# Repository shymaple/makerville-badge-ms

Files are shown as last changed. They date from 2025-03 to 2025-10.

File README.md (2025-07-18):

- `mkdir badge-workspace`
- `cd badge-workspace`
- `west init -m git@github.com:makerville/makerville-badge.git --mr master`
- `west update`
- `west packages pip --install`
- `west sdk install -t riscv64-zephyr-elf`
- `west blobs fetch hal_espressif`
- `cd makerville-badge`
- `make`
- `make flash monitor`

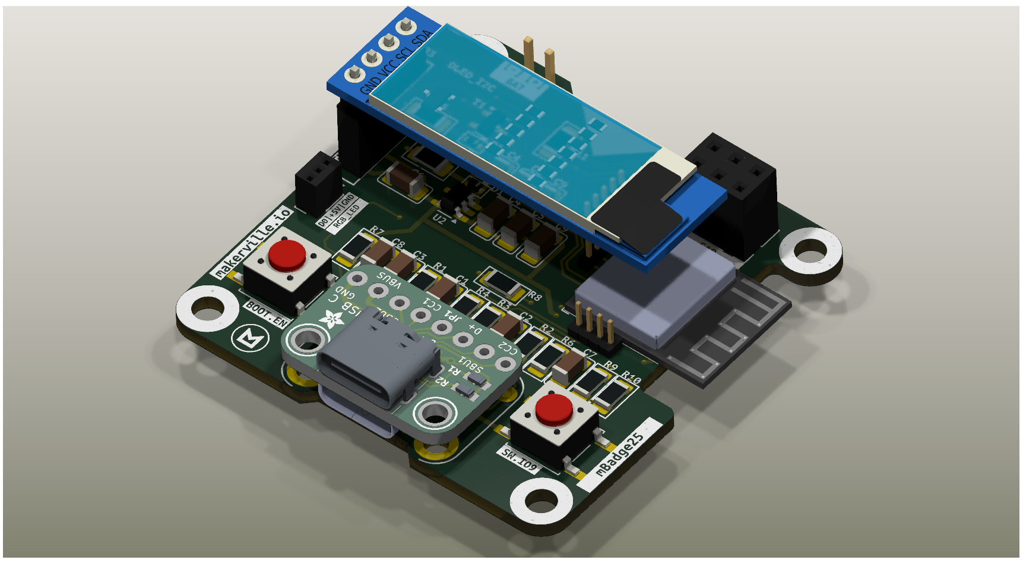
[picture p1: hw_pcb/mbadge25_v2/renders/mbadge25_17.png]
mBadge25_TOP


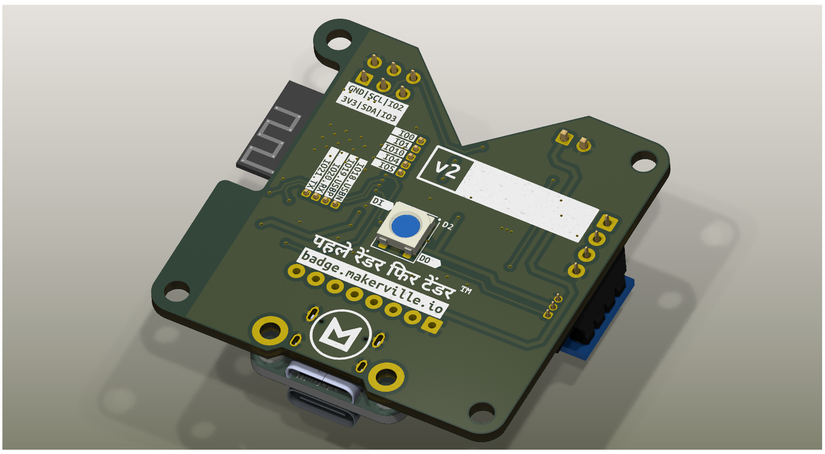
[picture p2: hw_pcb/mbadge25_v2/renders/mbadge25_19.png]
mBadge25_BOT


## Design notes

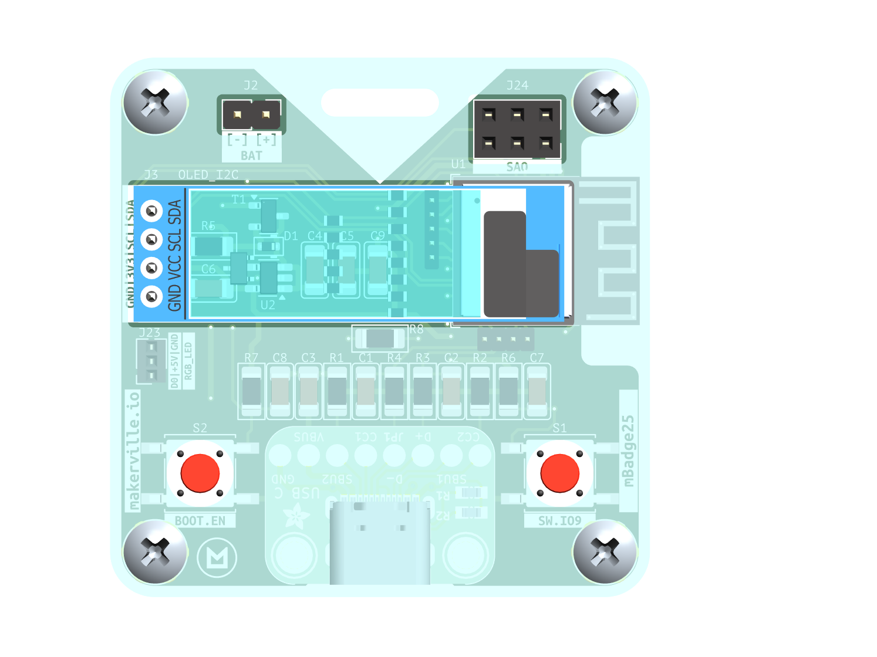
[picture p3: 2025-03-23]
hw_cad/renders/case_04.png

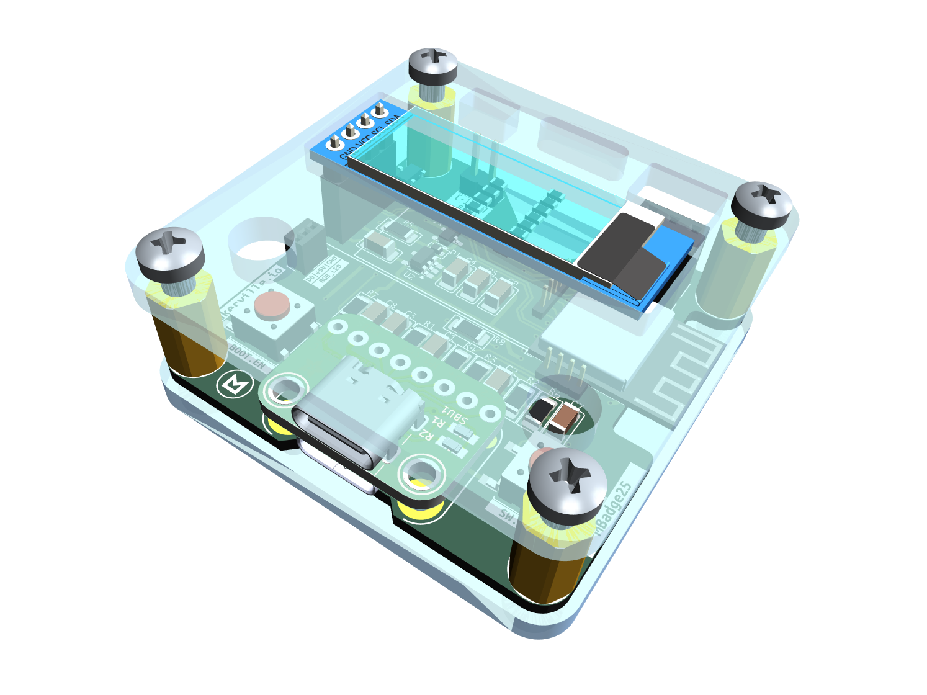
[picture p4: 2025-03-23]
hw_cad/renders/case_02.png

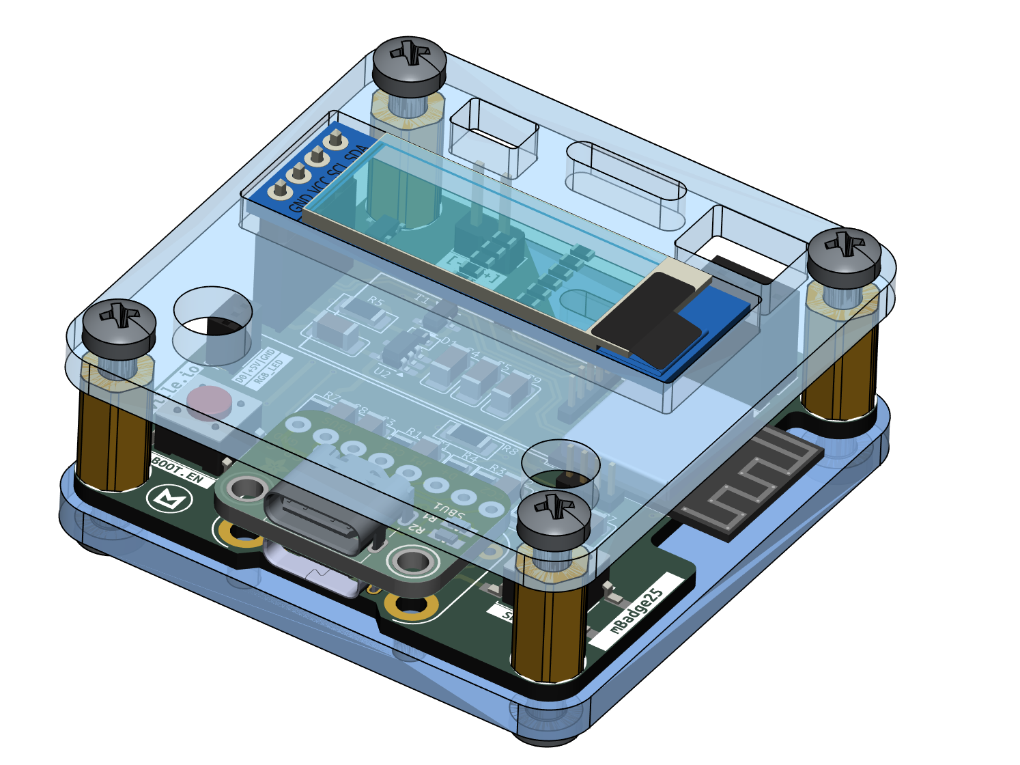
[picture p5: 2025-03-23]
hw_cad/renders/case_01.png

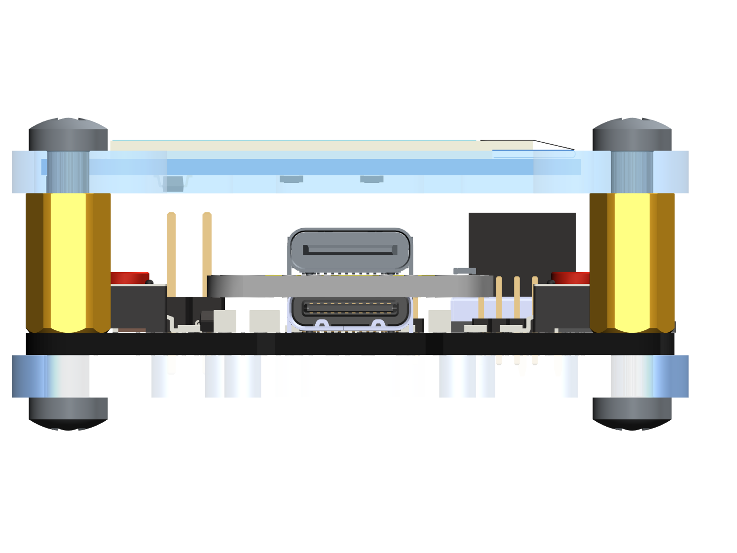
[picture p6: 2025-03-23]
hw_cad/renders/case_03.png

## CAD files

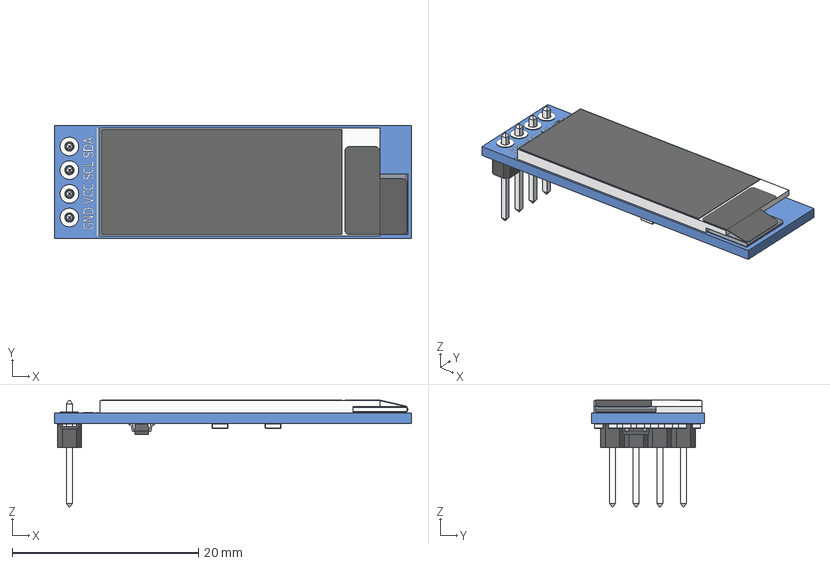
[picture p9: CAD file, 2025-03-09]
datasheets/OLED_0.91_128x32.stp
38.3 x 12.1 x 11.5 mm
OLED_0.91_128x32
Pin Header 4 x 1 TH 2.54mm Pitch
RESC-0603 x 13
2SD0601A

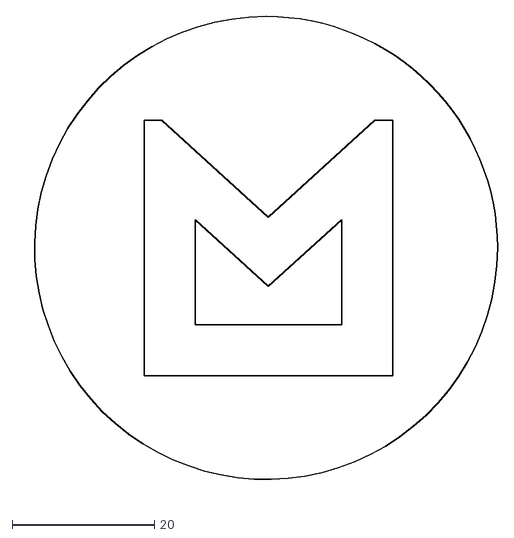
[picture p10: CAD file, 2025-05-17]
hw_pcb/mbadge25_v2/assets/makerville_logo.dxf
67.7 x 67.7

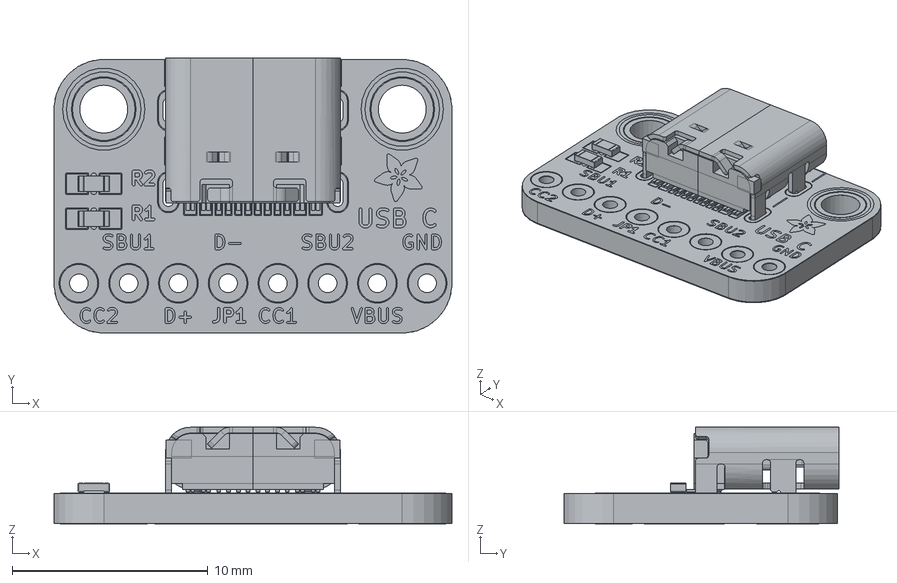
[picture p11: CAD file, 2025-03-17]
hw_pcb/USB-C_breakout/USB-C_BO.FCStd
20.3 x 14.0 x 4.98 mm
R_0603_1608Metric
R_0603_1608Metric001
USB_C_Receptacle_GCT_USB4105-xx-A_16P_TopMnt_Horizontal
USB_C_Receptacle_GCT_USB4105-xx-A_16P_TopMnt_Horizontal001
USB_C_Receptacle_GCT_USB4105-xx-A_16P_TopMnt_Horizontal002
USB_C_Receptacle_GCT_USB4105-xx-A_16P_TopMnt_Horizontal003
USB_C_Receptacle_GCT_USB4105-xx-A_16P_TopMnt_Horizontal004
USB_C_Receptacle_GCT_USB4105-xx-A_16P_TopMnt_Horizontal005
USB_C_Receptacle_GCT_USB4105-xx-A_16P_TopMnt_Horizontal006
USB_C_Receptacle_GCT_USB4105-xx-A_16P_TopMnt_Horizontal007
USB_C_Receptacle_GCT_USB4105-xx-A_16P_TopMnt_Horizontal008
USB_C_Receptacle_GCT_USB4105-xx-A_16P_TopMnt_Horizontal009
USB_C_Receptacle_GCT_USB4105-xx-A_16P_TopMnt_Horizontal010
USB_C_Receptacle_GCT_USB4105-xx-A_16P_TopMnt_Horizontal011
USB_C_Receptacle_GCT_USB4105-xx-A_16P_TopMnt_Horizontal012
USB_C_Receptacle_GCT_USB4105-xx-A_16P_TopMnt_Horizontal013
USB_C_Receptacle_GCT_USB4105-xx-A_16P_TopMnt_Horizontal014
USB_C_Receptacle_GCT_USB4105-xx-A_16P_TopMnt_Horizontal015
USB_C_Receptacle_GCT_USB4105-xx-A_16P_TopMnt_Horizontal016
USB_C_Receptacle_GCT_USB4105-xx-A_16P_TopMnt_Horizontal017
USB_C_Receptacle_GCT_USB4105-xx-A_16P_TopMnt_Horizontal018
USB_C_Receptacle_GCT_USB4105-xx-A_16P_TopMnt_Horizontal019
USB_C_Receptacle_GCT_USB4105-xx-A_16P_TopMnt_Horizontal020
USB_C_Receptacle_GCT_USB4105-xx-A_16P_TopMnt_Horizontal021
USB_C_Receptacle_GCT_USB4105-xx-A_16P_TopMnt_Horizontal022
USB_C_Receptacle_GCT_USB4105-xx-A_16P_TopMnt_Horizontal023
USB_C_Receptacle_GCT_USB4105-xx-A_16P_TopMnt_Horizontal024
USB_C_Receptacle_GCT_USB4105-xx-A_16P_TopMnt_Horizontal025
USB_C_Receptacle_GCT_USB4105-xx-A_16P_TopMnt_Horizontal026
USB_C_Receptacle_GCT_USB4105-xx-A_16P_TopMnt_Horizontal027
USB_C_Receptacle_GCT_USB4105-xx-A_16P_TopMnt_Horizontal028
USB_C_Receptacle_GCT_USB4105-xx-A_16P_TopMnt_Horizontal029
USB_C_Receptacle_GCT_USB4105-xx-A_16P_TopMnt_Horizontal030
USB_C_Receptacle_GCT_USB4105-xx-A_16P_TopMnt_Horizontal031
USB_C_Receptacle_GCT_USB4105-xx-A_16P_TopMnt_Horizontal032
USB_C_Receptacle_GCT_USB4105-xx-A_16P_TopMnt_Horizontal033
USB_C_Receptacle_GCT_USB4105-xx-A_16P_TopMnt_Horizontal034
USB_C_Receptacle_GCT_USB4105-xx-A_16P_TopMnt_Horizontal035
Adafruit USB Type C Downstream Breakout rev B_copper
Adafruit USB Type C Downstream Breakout rev B_copper001
Adafruit USB Type C Downstream Breakout rev B_copper002
Adafruit USB Type C Downstream Breakout rev B_copper003
Adafruit USB Type C Downstream Breakout rev B_copper004
Adafruit USB Type C Downstream Breakout rev B_copper005
Adafruit USB Type C Downstream Breakout rev B_copper006
Adafruit USB Type C Downstream Breakout rev B_copper007
Adafruit USB Type C Downstream Breakout rev B_copper008
Adafruit USB Type C Downstream Breakout rev B_copper009
Adafruit USB Type C Downstream Breakout rev B_copper010
Adafruit USB Type C Downstream Breakout rev B_copper011
Adafruit USB Type C Downstream Breakout rev B_pad
Adafruit USB Type C Downstream Breakout rev B_pad001
Adafruit USB Type C Downstream Breakout rev B_pad002
Adafruit USB Type C Downstream Breakout rev B_pad003
Adafruit USB Type C Downstream Breakout rev B_pad004
Adafruit USB Type C Downstream Breakout rev B_pad005
Adafruit USB Type C Downstream Breakout rev B_pad006
Adafruit USB Type C Downstream Breakout rev B_pad007
Adafruit USB Type C Downstream Breakout rev B_pad008
Adafruit USB Type C Downstream Breakout rev B_pad009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

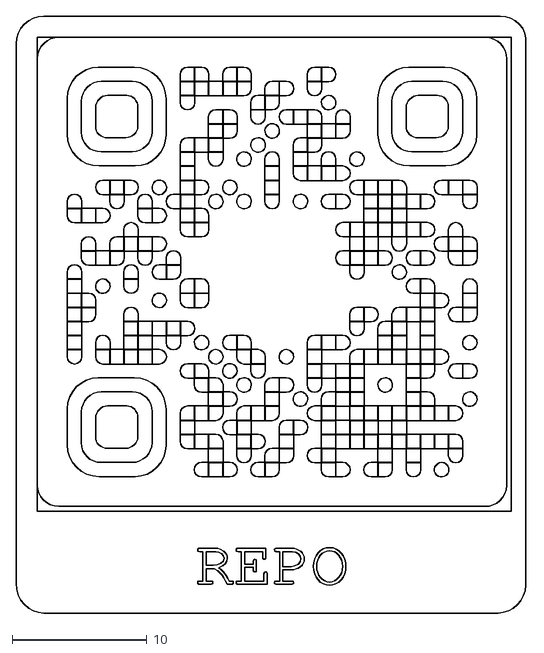
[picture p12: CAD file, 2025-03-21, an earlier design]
hw_pcb/mbadge25_v1/assets/MakervilleBadgeRepo.dxf
37.9 x 44.3

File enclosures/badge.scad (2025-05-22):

include <jl_scad/box.scad>
include <jl_scad/parts.scad>
include <jl_scad/utils.scad>
$fs = $preview?0.5:0.125;
$fa = 1;

$slop = 0.08;
box_sz = [47.5,47.5,10];
$box_outside_color = "#fffb";
$box_inside_color = "#9a9b";
$box_cut_color = "#0000";

// halves=[BOT]
box_make(print=true)
box_shell_base_lid(box_sz,rsides=6,wall_sides=1.6,wall_top=2,base_height=3,rim_height=2,rbot_inside=1,rtop_inside=1)
{
    size = $parent_size;

    // usb c 
    translate([0,0,3])box_part(TOP+FRONT)  box_cutout(rect([12,6]),depth=2,anchor=CENTER);

    // bat cables
    translate([0,0,0])box_part(TOP+BACK)  box_cutout(rect([5,2]),depth=2);

    // display
    translate([-2,12,0])box_part(TOP)  box_cutout(rect([27,12]),depth=2,anchor=FRONT);
    // text
     box_part(TOP, inside=false)
         translate([0,-7,0])Z(-0.4) box_cut() text3d("Makerville", h=2, size=7, atype="ycenter", anchor=BOTTOM);
    // vents
    X(11) box_cut() //for(a = [BACK,FRONT])
        box_part(LEFT) xcopies(3,4,sp=0) cuboid([1.5,8,8],rounding=0.75,anchor=CENTER);

    // screw mounts
    for(a = [BACK+LEFT, FRONT+RIGHT, BACK+RIGHT, FRONT+LEFT])
        M(a * -0.5) position(a) box_screw_clamp(od=6.4,anchor=a,gap=2);
            
    // buttons
    translate([16,-13.5,0])box_part(TOP) box_cut() cyl(d=5,h=15,anchor=CENTER); 
    translate([-16,-13.5,0])box_part(TOP) box_cut() cyl(d=5,h=15,anchor=CENTER); 

}

// buttons
module push_button(){
cylinder(4,4/2,4/2);
cylinder(0.5,5.6/2,5.6/2);
}

translate([50,0,0])push_button();
translate([40,0,0])push_button();

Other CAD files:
hw_pcb/USB-C_breakout/Adafruit USB Type C Downstream Breakout rev B.step

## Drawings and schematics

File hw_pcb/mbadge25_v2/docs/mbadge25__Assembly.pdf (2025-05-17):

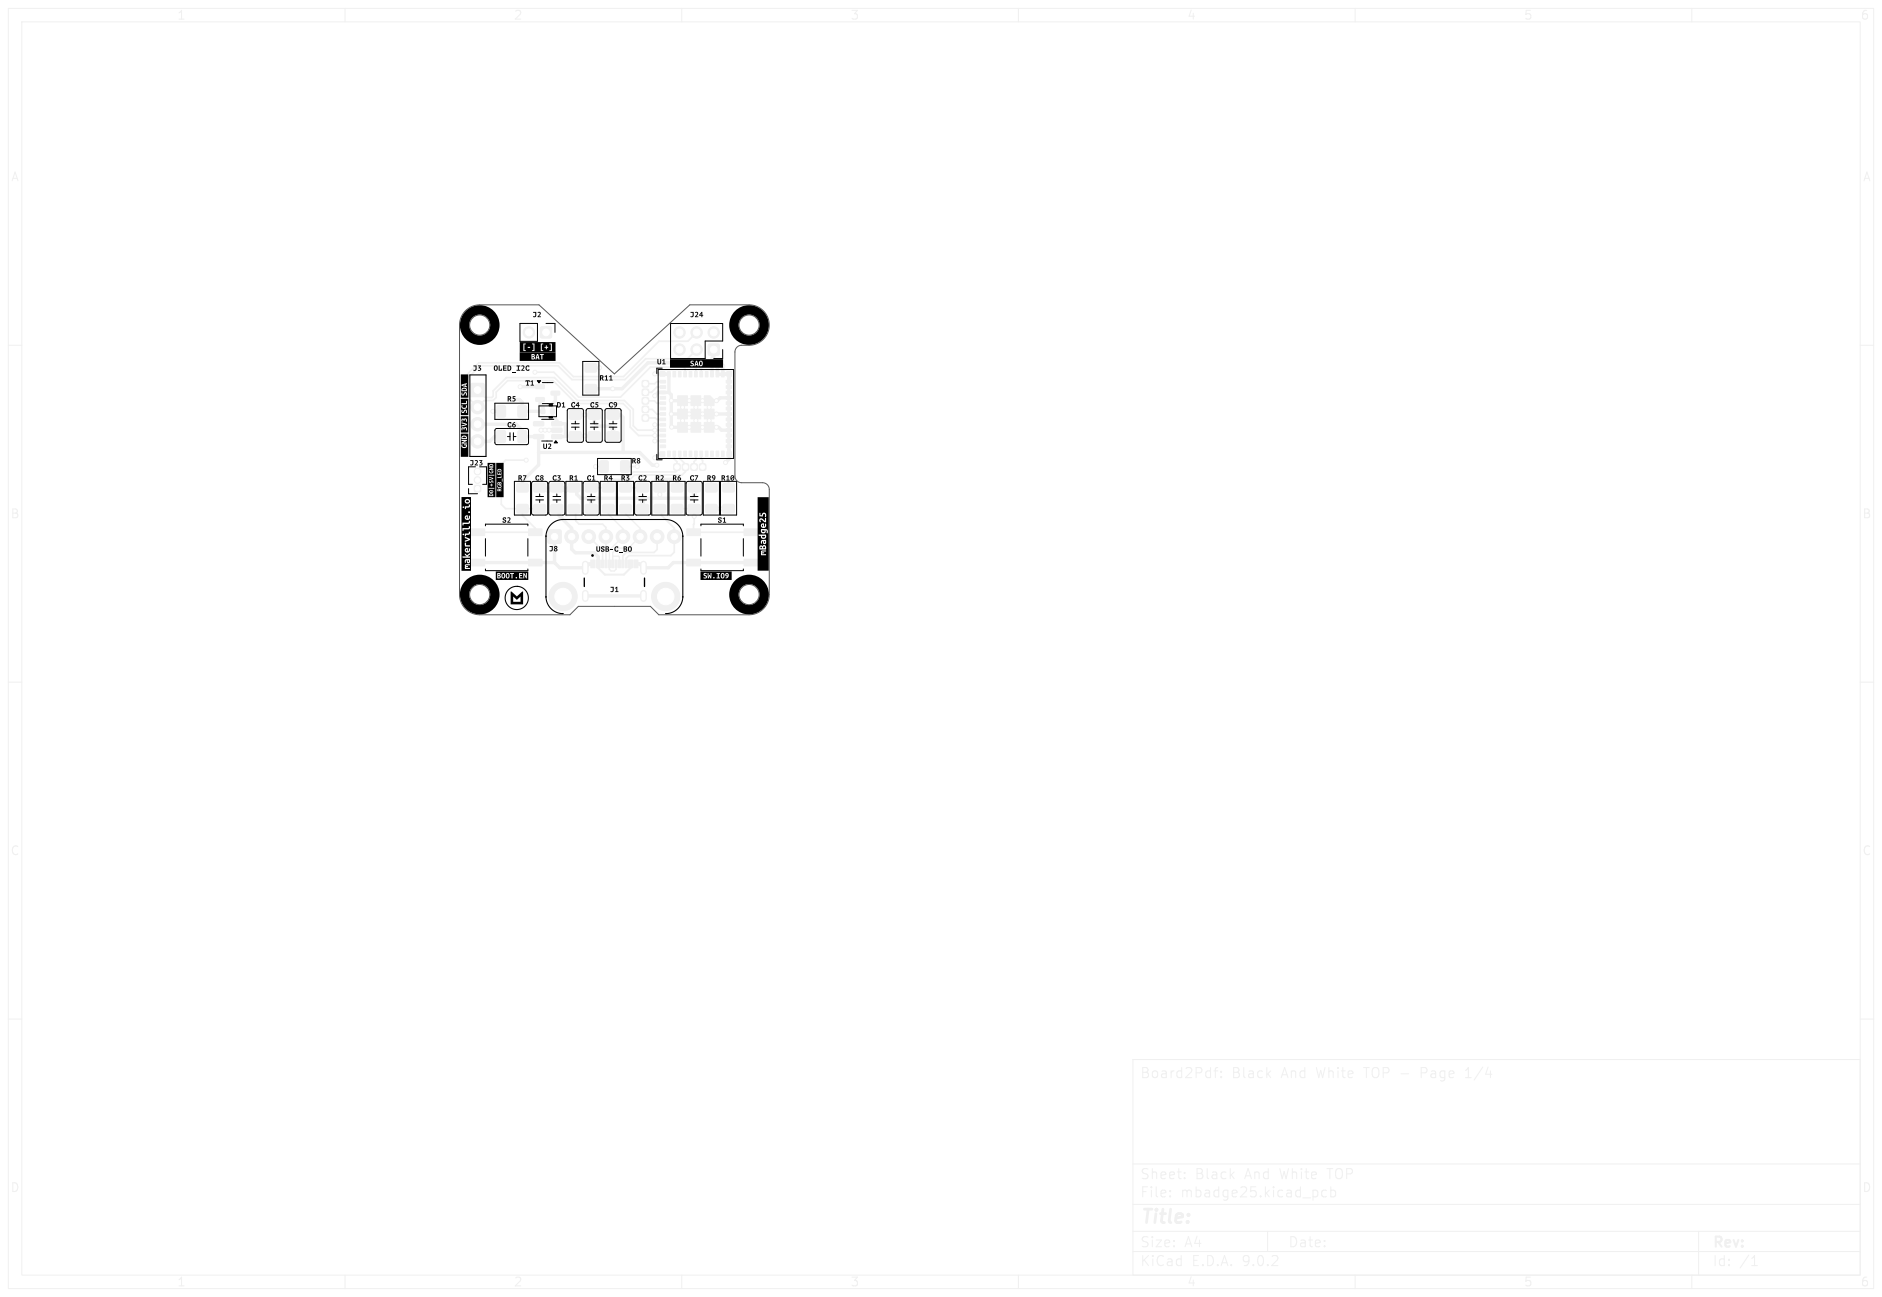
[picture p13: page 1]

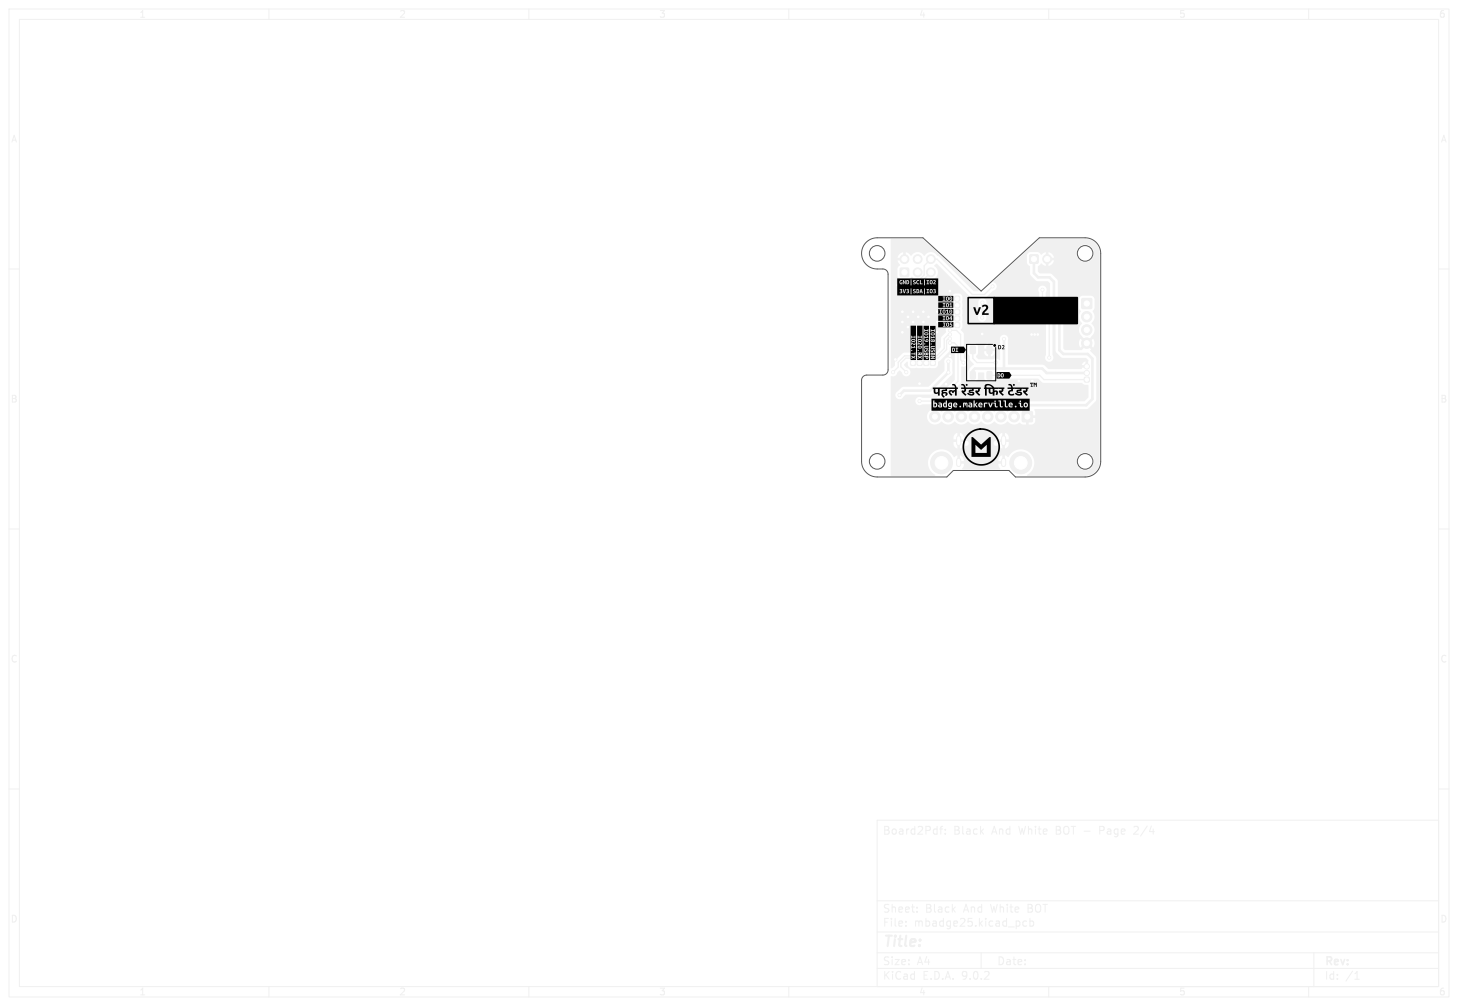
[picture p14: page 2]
D Date: KiCad; E.D.A. 9.0.2 Size: A4; Rev:; Id: /1 Title: File: mbadge25.kicad_pcb Sheet: Black; And; White; BOT Board2Pdf:; Black; BOT -; Page 2/4

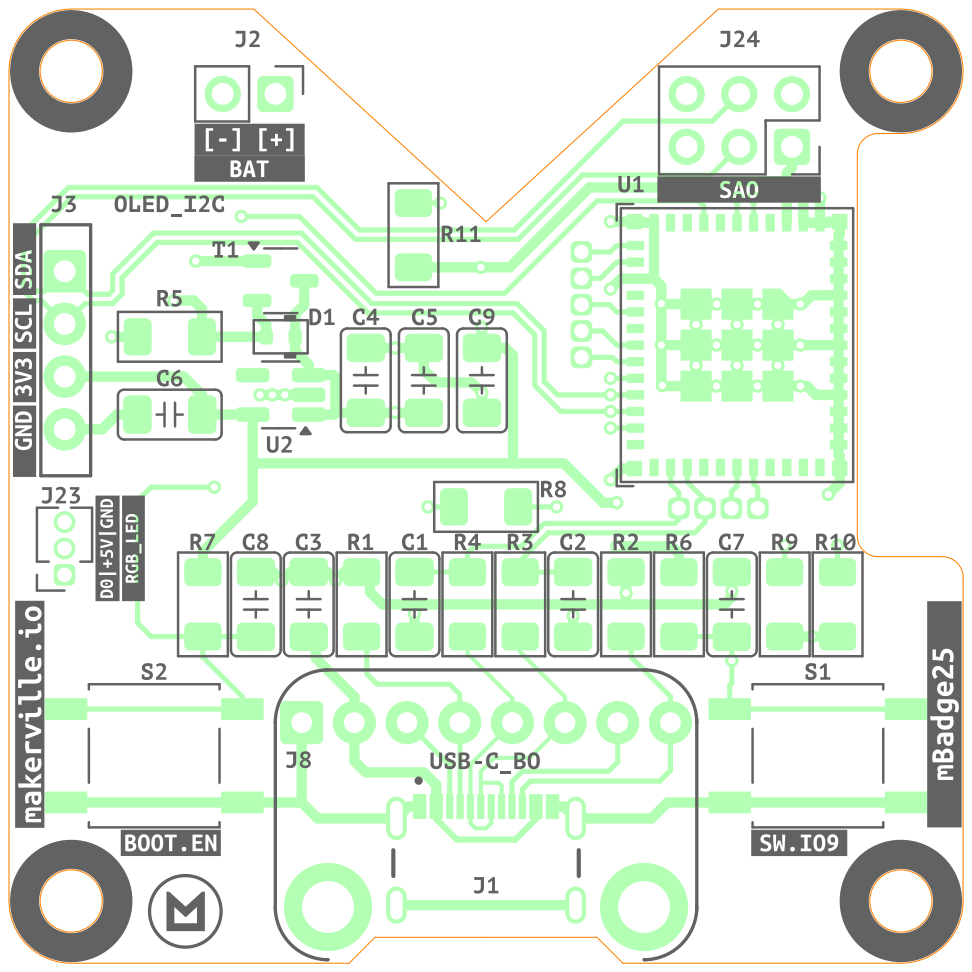
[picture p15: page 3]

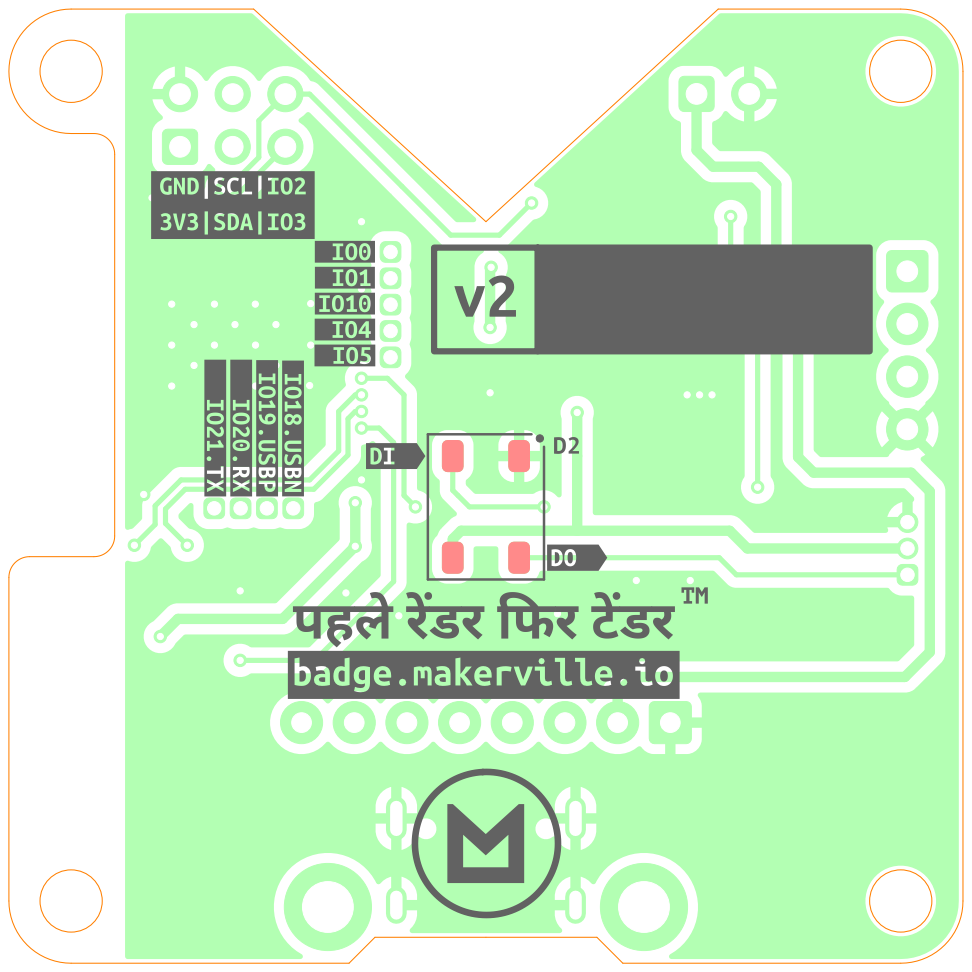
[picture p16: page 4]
D Date: KiCad; E.D.A. 9.0.2 Size: A4; Rev:; Id: /1 Title: File: mbadge25.kicad_pcb Sheet: Colored; BOT Board2Pdf:; Colored; BOT -; Page 4/4

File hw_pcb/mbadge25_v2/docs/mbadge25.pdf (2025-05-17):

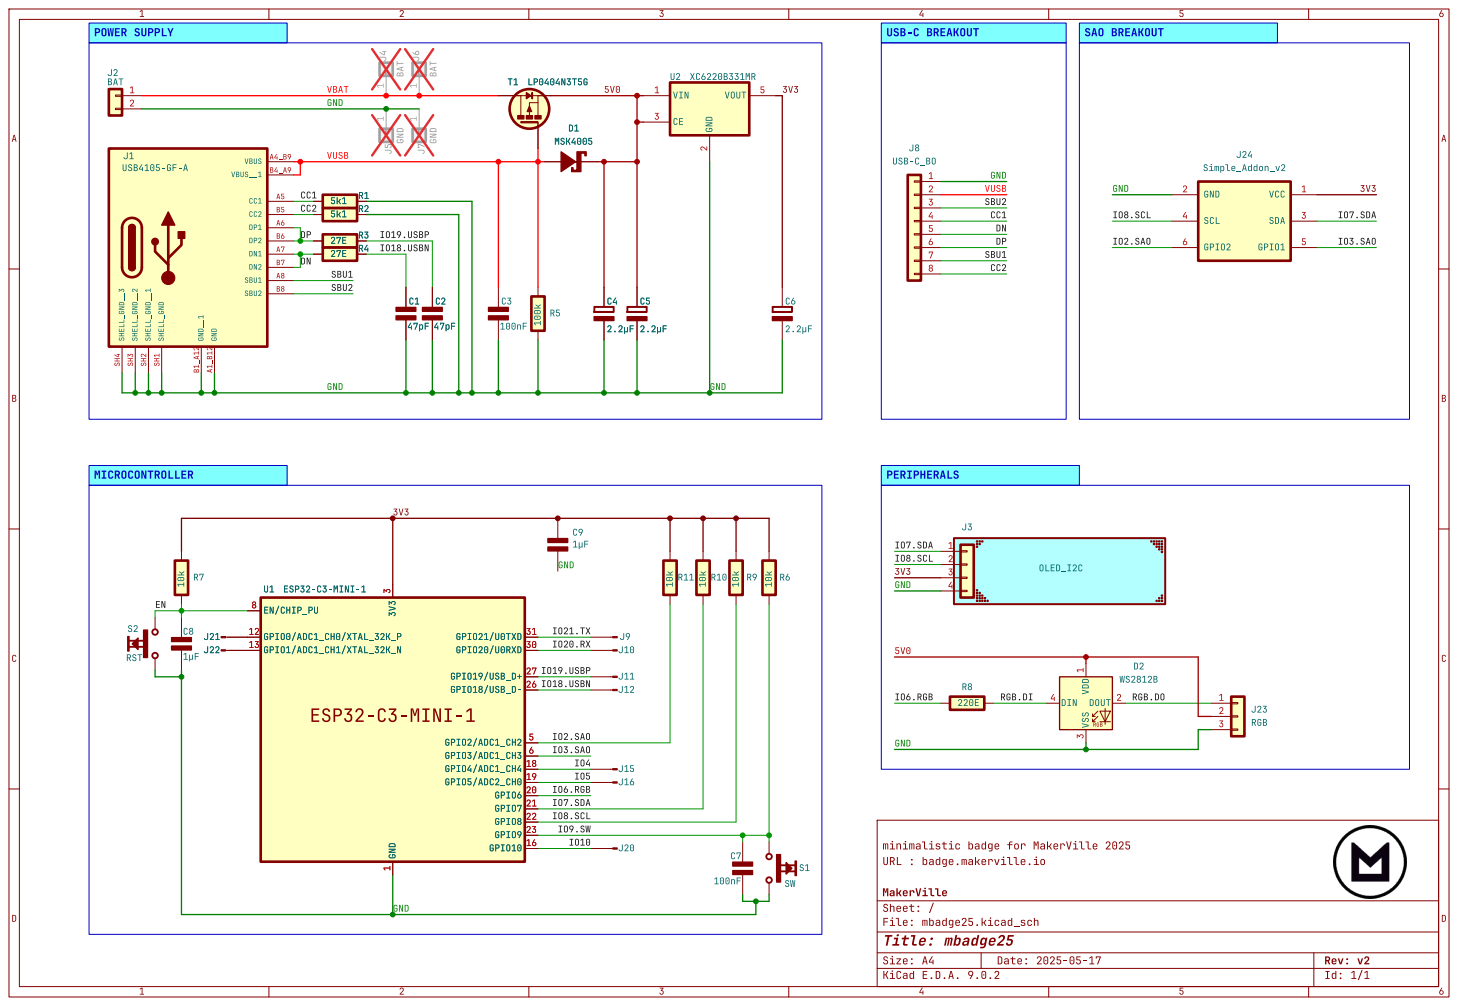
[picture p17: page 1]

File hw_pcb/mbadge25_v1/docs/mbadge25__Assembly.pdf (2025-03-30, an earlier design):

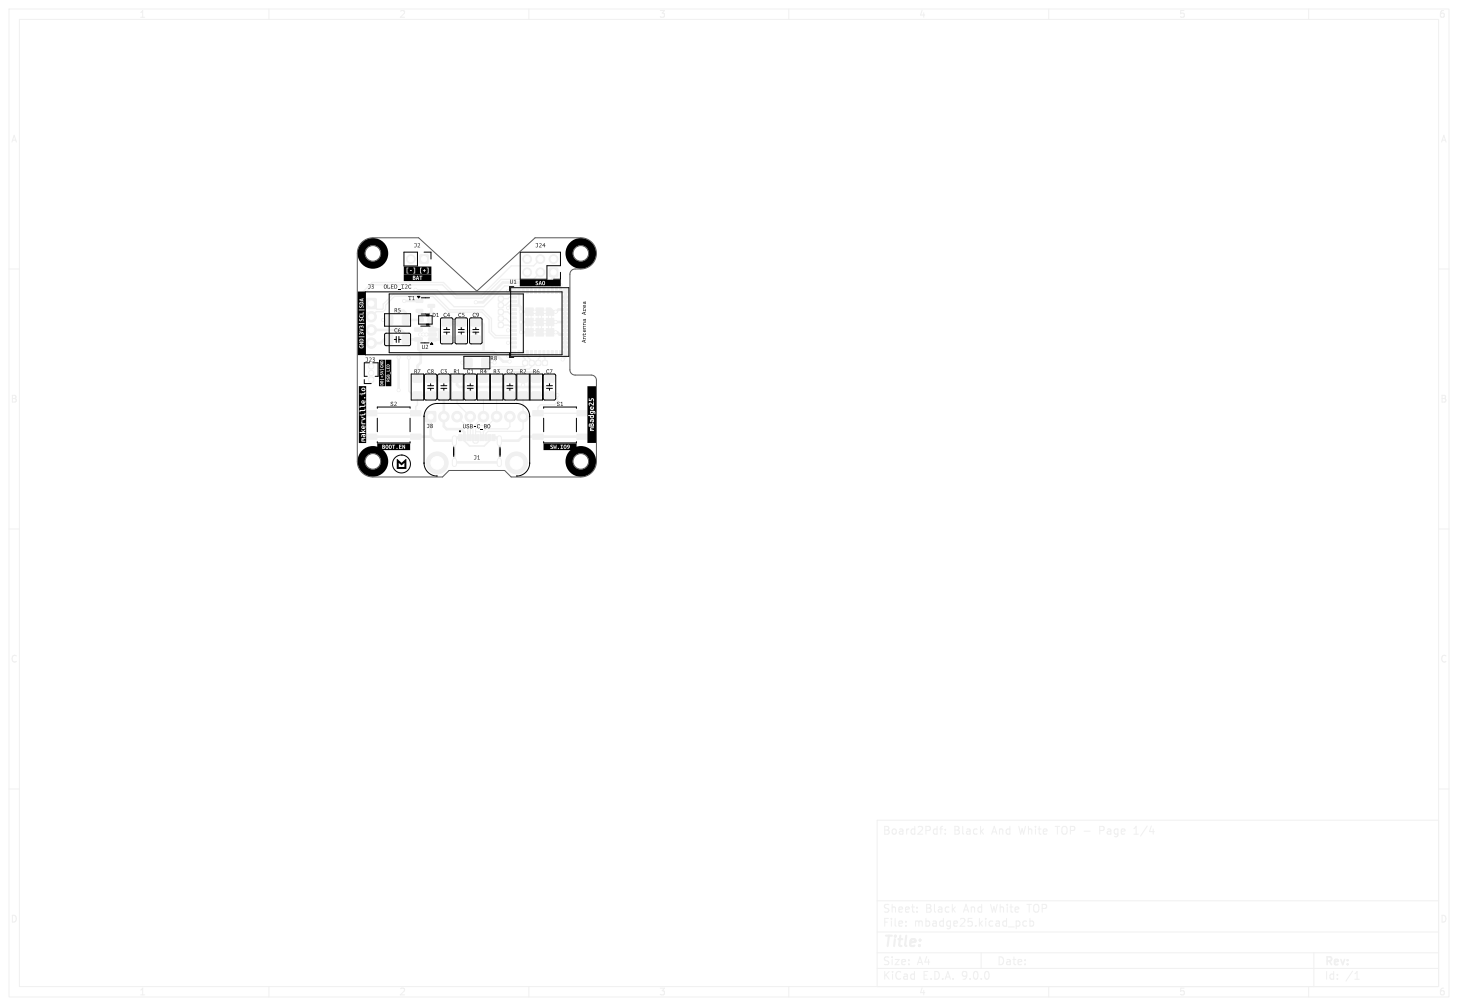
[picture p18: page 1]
D Date: KiCad; E.D.A. 9.0.0 Size: A4; Rev:; Id: /1 Title: File: mbadge25.kicad_pcb Sheet: Black; And; White; TOP; Board2Pdf:; Black; TOP -; Page

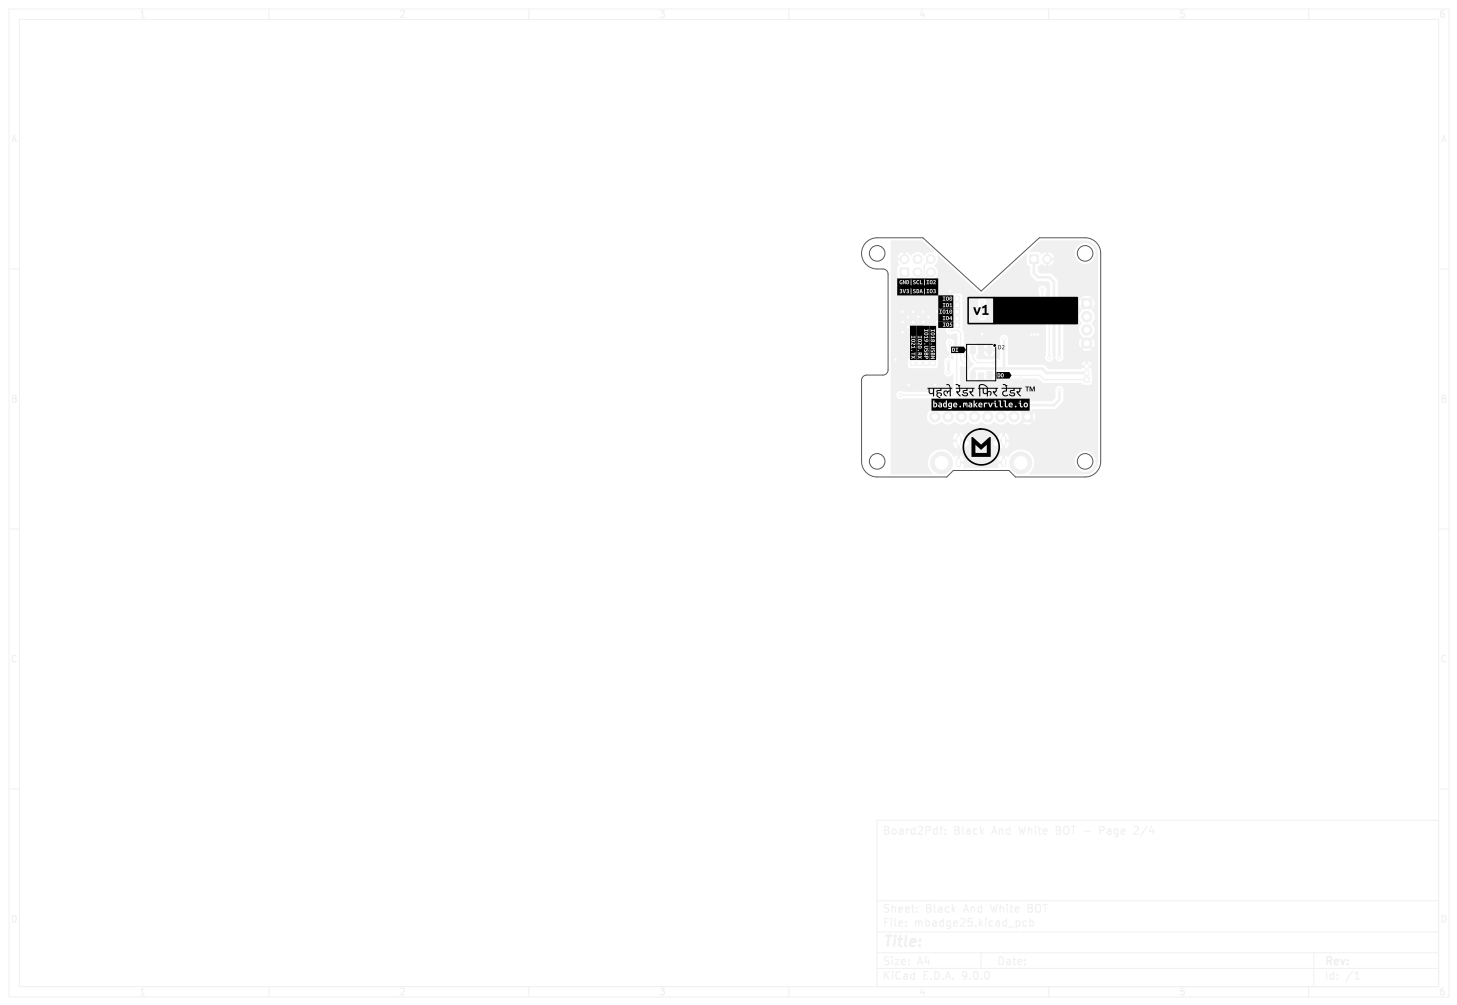
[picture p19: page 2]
D Date: KiCad; E.D.A. 9.0.0 Size: A4; Rev:; Id: /1 Title: File: mbadge25.kicad_pcb Sheet: Black; And; White; BOT Board2Pdf:; Black; BOT -; Page 2/4

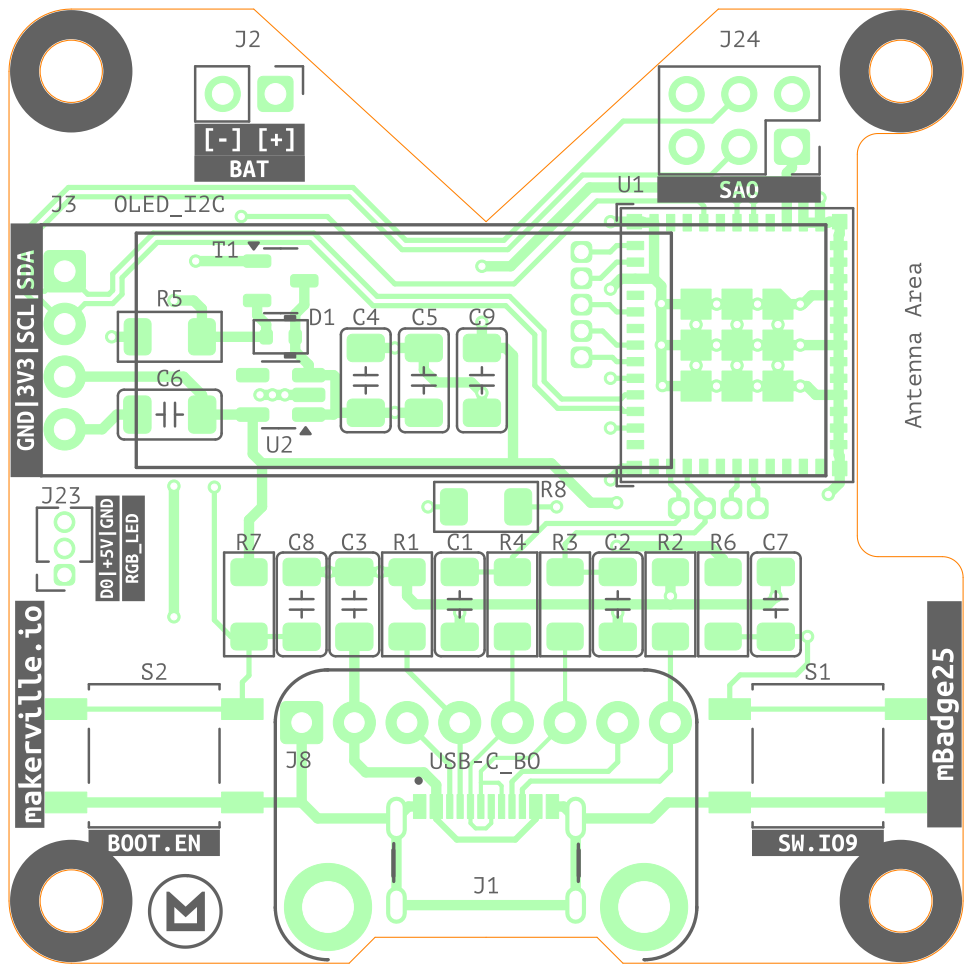
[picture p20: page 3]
D Date: KiCad; E.D.A. 9.0.0 Size: A4; Rev:; Id: /1 Title: File: mbadge25.kicad_pcb Sheet: Colored; TOP; Board2Pdf:; Colored; TOP -; Page 3/4

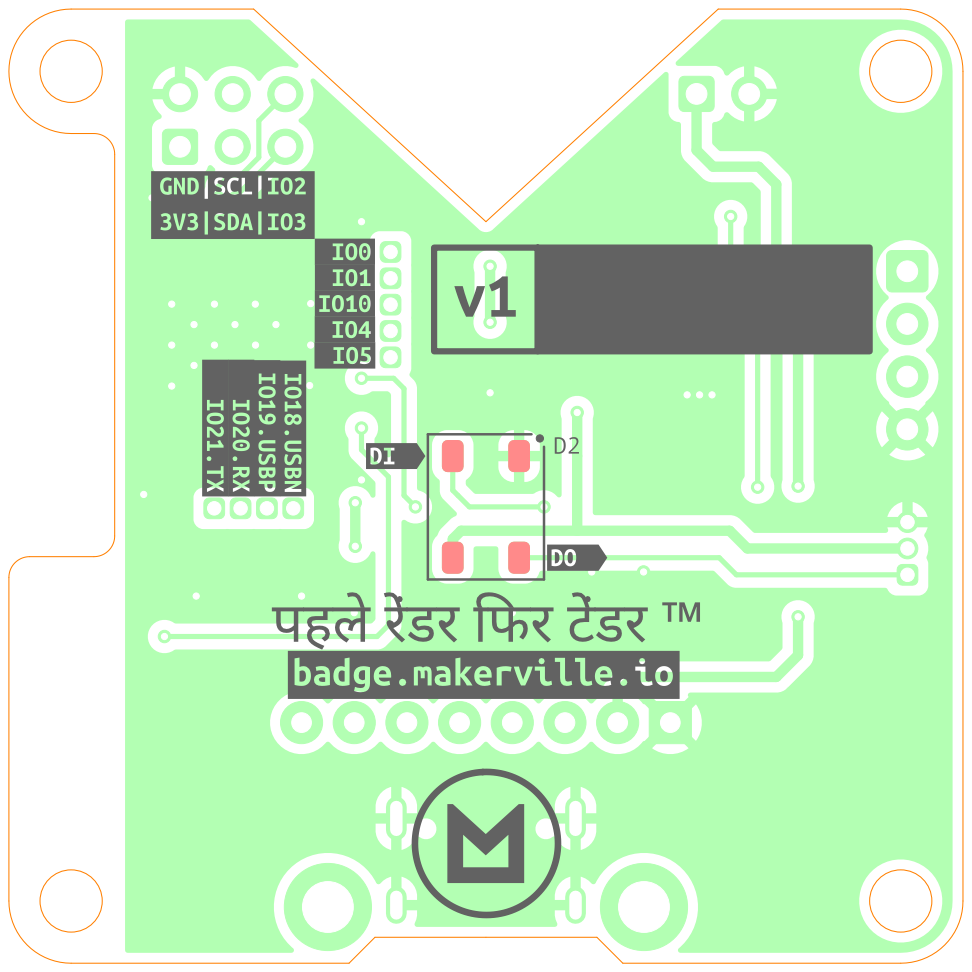
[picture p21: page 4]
D Date: KiCad; E.D.A. 9.0.0 Size: A4; Rev:; Id: /1 Title: File: mbadge25.kicad_pcb Sheet: Colored; BOT Board2Pdf:; Colored; BOT -; Page 4/4

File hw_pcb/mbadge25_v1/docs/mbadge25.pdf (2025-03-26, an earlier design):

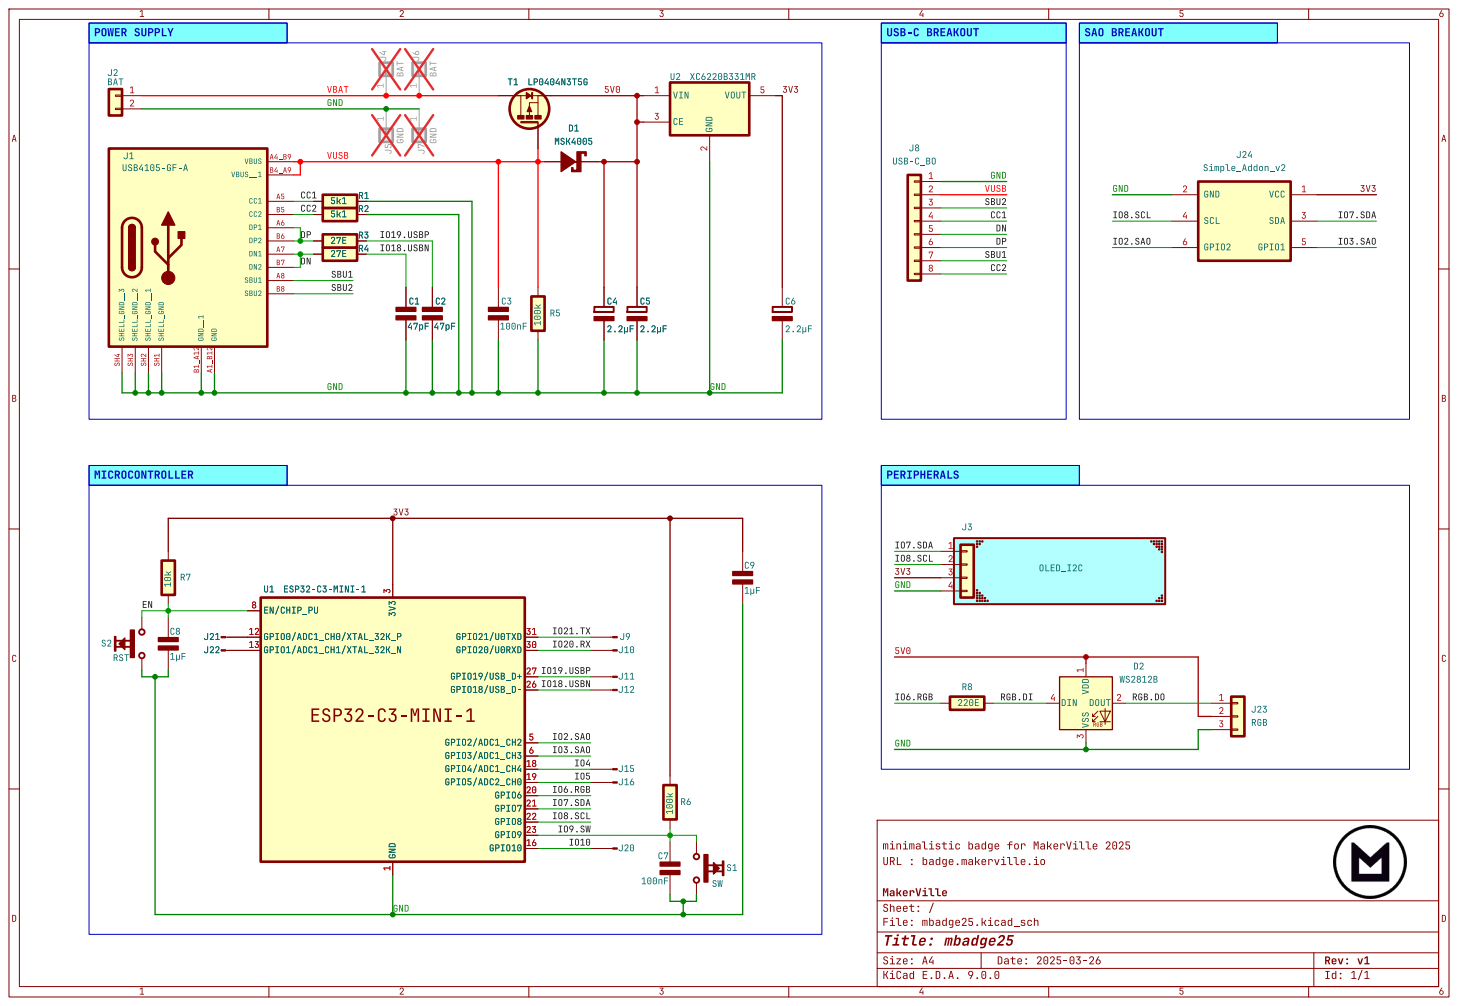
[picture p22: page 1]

EN/CHIP_PU | 31 GPIO20/U0RXD 31 GPIO20/U0RXD 30 GPIO19/USB_D+ 30 GPIO19/USB_D+ 27 GPIO18/USB_D-26 GPIO2/ADC1_CH2 27 GPIO18/USB_D-26 GPIO2/ADC1_CH2 5 GPIO3/ADC1_CH3 5 GPIO3/ADC1_CH3 6 GPIO4/ADC1_CH4 6 GPIO4/ADC1_CH4 18 GPIO5/ADC2_CH0 18 GPIO5/ADC2_CH0 19 GPIO6 19 GPIO6 20 GPIO7 20 GPIO7 21 GPIO8 21 GPIO8 22 GPIO9 22 GPIO9

23 GPIO10

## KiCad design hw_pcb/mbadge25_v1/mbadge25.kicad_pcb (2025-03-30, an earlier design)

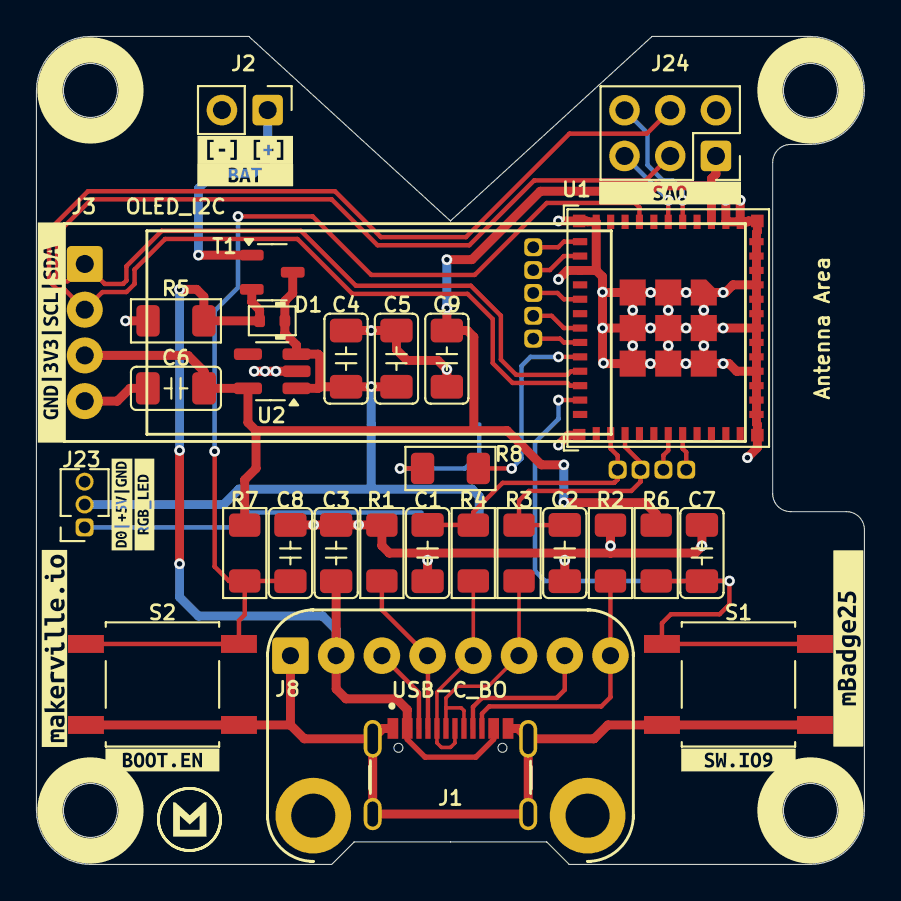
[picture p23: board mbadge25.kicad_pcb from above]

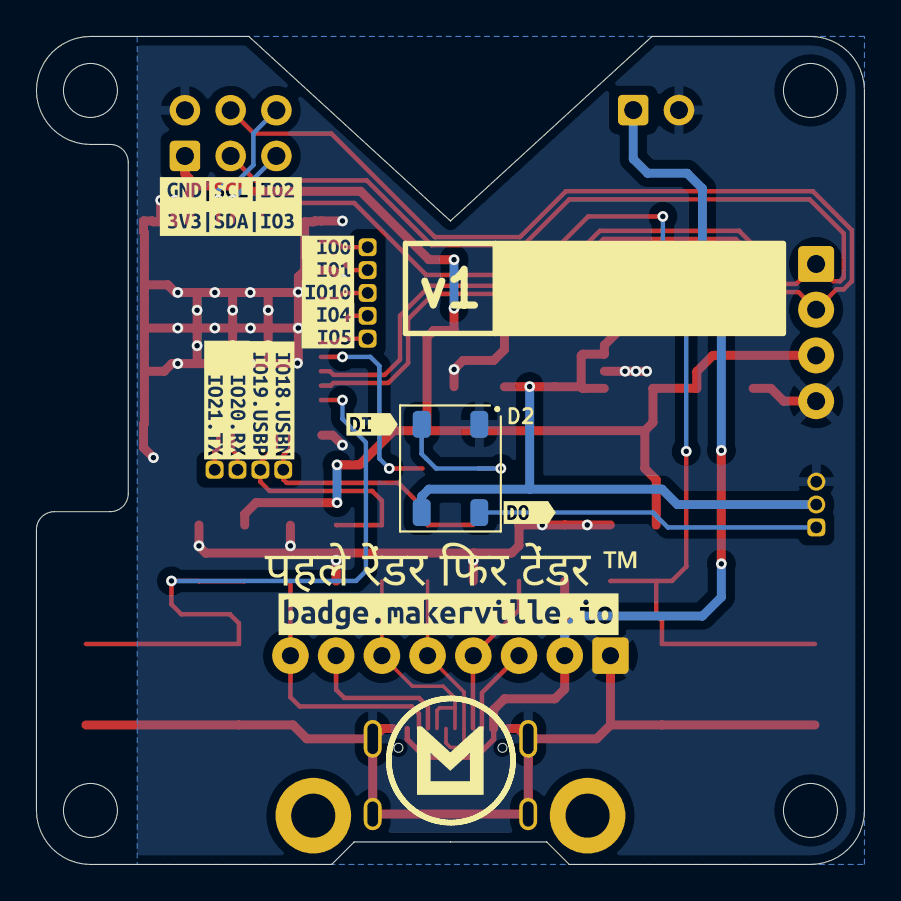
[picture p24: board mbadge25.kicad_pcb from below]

Board: 2 copper layers, 46.0 x 46.0 mm, 63 parts (15 on the bottom side), 29 nets.

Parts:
C1, C2: 47pF; C_1206_3216Metric_Pad1.33x1.80mm
C3, C7: 100nF; C_1206_3216Metric_Pad1.33x1.80mm
C4, C5, C6: 2.2µF; C_1206_3216Metric_Pad1.33x1.80mm
C8, C9: 1µF; C_1206_3216Metric_Pad1.33x1.80mm
D1: MSK4005; D_SOD-523
D2: WS2812B; LED_WS2812B_PLCC4_5.0x5.0mm_P3.2mm
J1: USB4105-GF-A; GCT_USB4105-GF-A
J2: BAT; PinHeader_1x02_P2.54mm_Vertical
J3: OLED_I2C; OLED_128x32
J8: USB-C_BO; USB_C_BO
J9: Conn_IO21.TX; PinHeader_1x01_P1.27mm_Vertical
J10: Conn_IO20.RX; PinHeader_1x01_P1.27mm_Vertical
J11: Conn_IO19.USBP; PinHeader_1x01_P1.27mm_Vertical
J12: Conn_IO18.USBN; PinHeader_1x01_P1.27mm_Vertical
J15: Conn_IO4; PinHeader_1x01_P1.27mm_Vertical
J16: Conn_IO5; PinHeader_1x01_P1.27mm_Vertical
J20: Conn_IO10; PinHeader_1x01_P1.27mm_Vertical
J21: Conn_IO00; PinHeader_1x01_P1.27mm_Vertical
J22: Conn_IO01; PinHeader_1x01_P1.27mm_Vertical
J23: RGB; PinSocket_1x03_P1.27mm_Vertical
J24: Simple_Addon_v2; PinSocket_2x03_P2.54mm_Vertical
R1, R2: 5k1; R_1206_3216Metric_Pad1.30x1.75mm
R3, R4: 27E; R_1206_3216Metric_Pad1.30x1.75mm
R5, R6: 100k; R_1206_3216Metric_Pad1.30x1.75mm
R7: 10k; R_1206_3216Metric_Pad1.30x1.75mm
R8: 220E; R_1206_3216Metric_Pad1.30x1.75mm
S1: SW; SW_SPST
S2: RST; SW_SPST
T1: LP0404N3T5G; SOT-23-3
U1: ESP32-C3-MINI-1
U2: XC6220B331MR; SOT-23-5_HandSoldering
kibuzzard-67DC6E7C: G***; kibuzzard-67DC6E7C
kibuzzard-67DC6E31: G***; kibuzzard-67DC6E31
kibuzzard-67DC7C6A: G***; kibuzzard-67DC7C6A
kibuzzard-67DC7C9D: G***; kibuzzard-67DC7C9D
kibuzzard-67DC74C1: G***; kibuzzard-67DC74C1
kibuzzard-67DC7196: G***; kibuzzard-67DC7196
kibuzzard-67DC7478: G***; kibuzzard-67DC7478
kibuzzard-67DC7585: G***; kibuzzard-67DC7585
kibuzzard-67DDA9CA: G***; kibuzzard-67DDA9CA
kibuzzard-67DDA805: G***; kibuzzard-67DDA805
kibuzzard-67DDAA0B: G***; kibuzzard-67DDAA0B
kibuzzard-67DDAEB0: G***; kibuzzard-67DDAEB0
kibuzzard-67DDB00D: G***; kibuzzard-67DDB00D
kibuzzard-67DDB002: G***; kibuzzard-67DDB002
kibuzzard-67DDB04A: G***; kibuzzard-67DDB04A
kibuzzard-67DDB008: G***; kibuzzard-67DDB008
kibuzzard-67DDB012: G***; kibuzzard-67DDB012
kibuzzard-67DDB018: G***; kibuzzard-67DDB018
kibuzzard-67DDB039: G***; kibuzzard-67DDB039
kibuzzard-67DDB040: G***; kibuzzard-67DDB040
kibuzzard-67DDB045: G***; kibuzzard-67DDB045
kibuzzard-67E1BB32: G***; kibuzzard-67E1BB32
kibuzzard-67E02D12: G***; kibuzzard-67E02D12
kibuzzard-67E616D7: G***; kibuzzard-67E616D7

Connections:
/3V3: C6.1 (+), C9.1 (+), J3.3, J24.1 (VCC), R6.2 (-), R7.2 (-), U1.3 (3V3), U2.5 (VOUT)
/5V0: C4.1 (+), C5.1 (+), D1.1 (K-), D2.1 (VDD), J23.2, T1.3 (S), U2.1 (VIN), U2.3 (CE)
/CC1: J1.A5 (CC1), J8.4, R1.1 (+)
/CC2: J1.B5 (CC2), J8.8, R2.1 (+)
/DN: J1.A7 (DN1), J1.B7 (DN2), J8.5, R4.1 (+)
/DP: J1.A6 (DP1), J1.B6 (DP2), J8.6, R3.1 (+)
/EN: C8.1 (+), R7.1 (+), S2.1, U1.8 (EN/CHIP_PU)
/GND: C1.2 (-), C2.2 (-), C3.2 (-), C4.2 (-), C5.2 (-), C6.2 (-), C7.2 (-), C8.2 (-), C9.2 (-), D2.3 (VSS), J1.A1_B12 (GND), J1.B1_A12 (GND__1), J1.SH1 (SHELL_GND), J1.SH2 (SHELL_GND__1), J1.SH3 (SHELL_GND__2), J1.SH4 (SHELL_GND__3), J2.2, J3.4, J8.1, J23.3, J24.2 (GND), R1.2 (-), R2.2 (-), R5.1 (+), S1.2, S2.2, U1.1 (GND), U1.2 (GND), U1.11 (GND), U1.14 (GND), U1.36 (GND), U1.37 (GND), U1.38 (GND), U1.39 (GND), U1.40 (GND), U1.41 (GND), U1.42 (GND), U1.43 (GND), U1.44 (GND), U1.45 (GND), U1.46 (GND), U1.47 (GND), U1.48 (GND), U1.49 (GND), U1.50 (GND), U1.51 (GND), U1.52 (GND), U1.53 (GND), U2.2 (GND)
/IO2.SAO: J24.6 (GPIO2), U1.5 (GPIO2/ADC1_CH2)
/IO3.SAO: J24.5 (GPIO1), U1.6 (GPIO3/ADC1_CH3)
/IO4: J15.1, U1.18 (GPIO4/ADC1_CH4)
/IO5: J16.1, U1.19 (GPIO5/ADC2_CH0)
/IO6.RGB: R8.2 (-), U1.20 (GPIO6)
/IO7.SDA: J3.1, J24.3 (SDA), U1.21 (GPIO7)
/IO8.SCL: J3.2, J24.4 (SCL), U1.22 (GPIO8)
/IO9.SW: C7.1 (+), R6.1 (+), S1.1, U1.23 (GPIO9)
/IO10: J20.1, U1.16 (GPIO10)
/IO18.USBN: C1.1 (+), J12.1, R4.2 (-), U1.26 (GPIO18/USB_D-)
/IO19.USBP: C2.1 (+), J11.1, R3.2 (-), U1.27 (GPIO19/USB_D+)
/IO20.RX: J10.1, U1.30 (GPIO20/U0RXD)
/IO21.TX: J9.1, U1.31 (GPIO21/U0TXD)
/RGB.DI: D2.4 (DIN), R8.1 (+)
/RGB.DO: D2.2 (DOUT), J23.1
/SBU1: J1.A8 (SBU1), J8.7
/SBU2: J1.B8 (SBU2), J8.3
/VBAT: J2.1, T1.1 (D)
/VUSB: C3.1 (+), D1.2 (A+), J1.A4_B9 (VBUS), J1.B4_A9 (VBUS__1), J8.2, R5.2 (-), T1.2 (G)
unnamed: J21.1, U1.12 (GPIO0/ADC1_CH0/XTAL_32K_P)
unnamed: J22.1, U1.13 (GPIO1/ADC1_CH1/XTAL_32K_N)

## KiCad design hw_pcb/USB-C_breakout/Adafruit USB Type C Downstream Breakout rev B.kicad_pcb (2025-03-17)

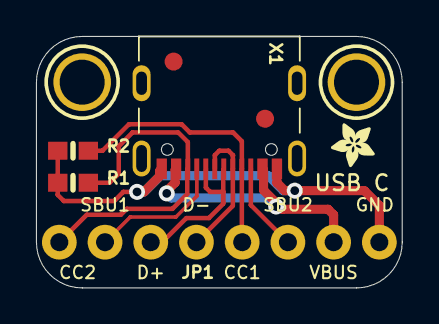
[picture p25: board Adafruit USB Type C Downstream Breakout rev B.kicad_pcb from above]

Board: 2 copper layers, 20.3 x 14.0 mm, 10 parts (1 on the bottom side), 8 nets.

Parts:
FID1, FID2: FIDUCIAL_1MM
JP1: 1X08_ROUND_76
R1, R2: 5.1K; 0603-NO
U$1, U$2: MOUNTINGHOLE2.5; MOUNTINGHOLE_2.5_PLATED
U$3: ADAFRUIT_2.5MM
U$8: PCBFEAT-REV-040
X1: USB_C_CUSB31-CFM2AX-01-X

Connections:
CC1: JP1.4, R2.2, X1.A5
CC2: JP1.8, R1.2, X1.B5
D+: JP1.6, X1.A6, X1.B6
D-: JP1.5, X1.A7, X1.B7
GND: JP1.1, R1.1, R2.1, X1.A1B12, X1.B1A12
SBU1: JP1.7, X1.A8
SBU2: JP1.3, X1.B8
VBUS: JP1.2, X1.A4B9, X1.B4A9

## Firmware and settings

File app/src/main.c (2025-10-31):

#include <zephyr/kernel.h>
#include <zephyr/logging/log.h>
#include <zephyr/drivers/display.h>
#include <zephyr/device.h>
#include <zephyr/devicetree.h>
#include <zephyr/display/cfb.h>
#include <zephyr/drivers/gpio.h>
#include <zephyr/smf.h>
#include <zephyr/input/input.h>
#include <zephyr/types.h>
#include <zephyr/sys/byteorder.h>
#include <zephyr/bluetooth/bluetooth.h>
#include <zephyr/bluetooth/hci.h>
#include <zephyr/bluetooth/conn.h>
#include <zephyr/bluetooth/uuid.h>
#include <zephyr/bluetooth/gatt.h>
#include <zephyr/shell/shell.h>
#include <zephyr/drivers/led_strip.h>
#include <string.h>
#define LOG_LEVEL LOG_LEVEL_DGB
LOG_MODULE_REGISTER(badge_shell);

#define STRIP_NODE  DT_ALIAS(led_strip)
#if !DT_NODE_HAS_STATUS(STRIP_NODE, okay)
#error "LED strip device not defined in devicetree"
#endif

#define STRIP_NUM_PIXELS DT_PROP(STRIP_NODE, chain_length)
#define LED_DELAY  K_MSEC(600)
#define RGB(_r, _g, _b) ((struct led_rgb) { .r = (_r), .g = (_g), .b = (_b)})
static const struct device *const strip = DEVICE_DT_GET(STRIP_NODE);

static struct led_rgb pixels[STRIP_NUM_PIXELS];

static void set_led_color(struct led_rgb color)
{
  for (int i = 0; i < STRIP_NUM_PIXELS; i++){
    pixels[i] = color;
  }
  int rc = led_strip_update_rgb(strip, pixels, STRIP_NUM_PIXELS);
  if(rc){
    LOG_ERR("led strip update failed: %d",rc);
  }else{
    LOG_INF("LED color set: R=%u G=%u B=%u", color.r, color.g, color.b);
  }
}

static int cmd_led(const struct shell *shell, size_t argc, char **argv)
{
  if (argc != 4){
    shell_print(shell, "Usage: led <red> <green> <blue> (each 0-255)");
    return -EINVAL;
  }

  char *endptr;
  long r = strtol(argv[1], &endptr, 10);
  if (*endptr != '\0' || r < 0 || r > 255) {
    shell_error(shell, "Invalid red value (0-255)");
    return -EINVAL;
  }
  long g = strtol(argv[2], &endptr, 10);
  if (*endptr != '\0' || g < 0 || g > 255) {
    shell_error(shell, "Invalid green value (0-255)");
    return -EINVAL;
  }
  long b = strtol(argv[3], &endptr, 10);
  if (*endptr != '\0' || b < 0 || b > 255) {
    shell_error(shell, "Invalid blue value (0-255)");
    return -EINVAL;
  }

  set_led_color(RGB((uint8_t)r, (uint8_t)g, (uint8_t)b));
  return 0;
}
SHELL_CMD_REGISTER(led, NULL, "Set LED color (r, g, b)", cmd_led);


static const struct smf_state badge_states[];

enum badge_state {
  BADGE_STATE_INIT,
  BADGE_STATE_IDLE,
  BADGE_STATE_ERROR,
};

enum badge_event {
  BADGE_EVENT_DISPLAY_ERROR,
  BADGE_EVENT_BLE_ERROR,
  BADGE_EVENT_SHORT_BUTTON_PRESS,
  BADGE_EVENT_LONG_BUTTON_PRESS,
};

// Forward declarations
void display_text(char* text);
void gen_event(enum badge_event event);

struct global_context{
  int64_t button_press_time;
} gc;

K_MSGQ_DEFINE(event_msgq, sizeof(enum badge_event), 10,1);

struct s_object {
  struct smf_ctx ctx;
  enum badge_event event;
}s_obj;

//LOG_MODULE_REGISTER(BADGE, LOG_LEVEL_DBG);
const struct device *display_dev;

// Define work queue for display operations
K_THREAD_STACK_DEFINE(display_stack, 1024);
struct k_work_q display_work_q;

// Structure to hold display text work
struct display_work_item {
    struct k_work work;
    char text[32];
    bool update_text;
};

// Create a single work item that we'll reuse
static struct display_work_item display_item;

// BLE service UUIDs
#define BADGE_SERVICE_UUID 0x1234
#define BADGE_CHARACTERISTIC_UUID 0x5678

// BLE service data
static uint8_t badge_data[32] = "Makerville Badge MS";

// Read callback for the characteristic
static ssize_t read_badge_data(struct bt_conn *conn,
                             const struct bt_gatt_attr *attr,
                             void *buf, uint16_t len, uint16_t offset)
{
    return bt_gatt_attr_read(conn, attr, buf, len, offset, badge_data,
                            strlen(badge_data));
}

// Write callback for the characteristic
static ssize_t write_badge_data(struct bt_conn *conn,
                              const struct bt_gatt_attr *attr,
                              const void *buf, uint16_t len, uint16_t offset,
                              uint8_t flags)
{
    if (offset + len > sizeof(badge_data)) {
        return BT_GATT_ERR(BT_ATT_ERR_INVALID_OFFSET);
    }

    memcpy(badge_data + offset, buf, len);
    badge_data[len] = '\0';  // Ensure null termination

    LOG_INF("Received data: %s", badge_data);
    display_text(badge_data);
    return len;
}

static struct bt_gatt_attr attrs[] = {
    BT_GATT_PRIMARY_SERVICE(BT_UUID_DECLARE_16(BADGE_SERVICE_UUID)),
    BT_GATT_CHARACTERISTIC(BT_UUID_DECLARE_16(BADGE_CHARACTERISTIC_UUID),
                          BT_GATT_CHRC_READ | BT_GATT_CHRC_WRITE,
                          BT_GATT_PERM_READ | BT_GATT_PERM_WRITE,
                          read_badge_data, write_badge_data, badge_data),
};

static struct bt_gatt_service badge_service = {
    .attrs = attrs,
    .attr_count = ARRAY_SIZE(attrs),
};

// Helper function to start advertising
static int start_advertising(void)
{
    int err;

    // Stop any existing advertising first
    err = bt_le_adv_stop();
    if (err) {
        LOG_ERR("Failed to stop advertising (err %d)", err);
        // Continue anyway as we want to try starting
    }

    struct bt_le_adv_param param = {
        .id = 0,
        .sid = 0,
        .secondary_max_skip = 0,
        .options = BT_LE_ADV_OPT_CONN  | BT_LE_ADV_OPT_USE_NAME,
        .interval_min = BT_GAP_ADV_FAST_INT_MIN_2,
        .interval_max = BT_GAP_ADV_FAST_INT_MAX_2,
        .peer = NULL,
    };
    /* wait for 1 second */
    k_msleep(1000);
    err = bt_le_adv_start(&param, NULL, 0, NULL, 0);
    if (err) {
        LOG_ERR("Advertising failed to start (err %d)", err);
        return err;
    }

    LOG_INF("Advertising started");
    return 0;
}

// BLE connection callback
static void connected(struct bt_conn *conn, uint8_t err)
{
    if (err) {
        LOG_ERR("Connection failed (err %u)", err);
        gen_event(BADGE_EVENT_BLE_ERROR);
    } else {
        LOG_INF("Connected");
    }
}

static void disconnected(struct bt_conn *conn, uint8_t reason)
{
    LOG_INF("Disconnected (reason %u)", reason);

    // Restart advertising
    int err = start_advertising();
    if (err) {
        LOG_ERR("Failed to restart advertising (err %d)", err);
        gen_event(BADGE_EVENT_BLE_ERROR);
    }
}

BT_CONN_CB_DEFINE(conn_callbacks) = {
    .connected = connected,
    .disconnected = disconnected,
};

// BLE initialization function
static int ble_init(void)
{
    int err;

    err = bt_enable(NULL);
    if (err) {
        LOG_ERR("Bluetooth init failed (err %d)", err);
        gen_event(BADGE_EVENT_BLE_ERROR);
        return err;
    }

    LOG_INF("Bluetooth initialized");

    err = bt_gatt_service_register(&badge_service);
    if (err) {
        LOG_ERR("Service registration failed (err %d)", err);
        gen_event(BADGE_EVENT_BLE_ERROR);
        return err;
    }

    return start_advertising();
}

/* Send a message to the display thread */
void message_display_thread(char* text)
{
  LOG_INF("Message display thread");
}

void gen_event(enum badge_event event)
{
  k_msgq_put(&event_msgq, (void*)&event, K_NO_WAIT);
}

int display_init()
{
  uint16_t x_res;
	uint16_t y_res;
	uint16_t rows;
	uint8_t ppt;

	if (display_set_pixel_format(display_dev, PIXEL_FORMAT_MONO10) != 0) {
		if (display_set_pixel_format(display_dev, PIXEL_FORMAT_MONO01) != 0) {
			printf("Failed to set required pixel format");
			return 0;
		}
	}

	printf("Initialized %s\n", display_dev->name);

	if (cfb_framebuffer_init(display_dev)) {
		printf("Framebuffer initialization failed!\n");
		return 0;
	}

	cfb_framebuffer_clear(display_dev, true);

	display_blanking_off(display_dev);

	x_res = cfb_get_display_parameter(display_dev, CFB_DISPLAY_WIDTH);
	y_res = cfb_get_display_parameter(display_dev, CFB_DISPLAY_HEIGHT);
	rows = cfb_get_display_parameter(display_dev, CFB_DISPLAY_ROWS);
	ppt = cfb_get_display_parameter(display_dev, CFB_DISPLAY_PPT);

	/* for (int idx = 0; idx < 42; idx++) { */
	/* 	if (cfb_get_font_size(display_dev, idx, &font_width, &font_height)) { */
	/* 		break; */
	/* 	} */
	/* 	cfb_framebuffer_set_font(display_dev, idx); */
	/* 	printf("font width %d, font height %d\n", */
	/* 	       font_width, font_height); */
  /*   if (idx==2) */
  /*     break; */
	/* } */
  cfb_framebuffer_set_font(display_dev, 2);

	printf("x_res %d, y_res %d, ppt %d, rows %d, cols %d\n",
	       x_res,
	       y_res,
	       ppt,
	       rows,
	       cfb_get_display_parameter(display_dev, CFB_DISPLAY_COLS));

	/* cfb_framebuffer_invert(display_dev); */

	cfb_set_kerning(display_dev, 0);
  return 0;
}

void display_work_handler(struct k_work *work)
{
    struct display_work_item *display_item = CONTAINER_OF(work, struct display_work_item, work);
    int x_res = cfb_get_display_parameter(display_dev, CFB_DISPLAY_WIDTH);
    int text_len = strlen(display_item->text);
    int char_width = 20; // Approximate width of each character
    int total_width = text_len * char_width;
    int x_pos = x_res; // Start from right edge

    // Clear the display once at the start
    cfb_framebuffer_clear(display_dev, true);

    while (1) {
        // Only clear the area that needs updating
        cfb_framebuffer_clear(display_dev, false);

        // Scroll the text from right to left
        while (x_pos > -total_width) {
            // Clear only the area that needs updating
            cfb_framebuffer_clear(display_dev, false);
            cfb_print(display_dev, display_item->text, x_pos, 0);
            cfb_framebuffer_finalize(display_dev);
            x_pos -= 4; // Faster scroll speed
            k_msleep(10); // Shorter delay between updates
        }

        // Reset position for next iteration
        x_pos = x_res;

        // If text was updated, break the loop to restart with new text
        if (display_item->update_text) {
            display_item->update_text = false;
            // Clear the display for the new text
            cfb_framebuffer_clear(display_dev, true);
            break;
        }
    }

    // Resubmit the work to continue scrolling
    k_work_submit_to_queue(&display_work_q, &display_item->work);
}

void display_text(char* text)
{
    // Copy the text to the work item
    strncpy(display_item.text, text, sizeof(display_item.text) - 1);
    display_item.text[sizeof(display_item.text) - 1] = '\0';
    display_item.update_text = true;

    // Submit the work to the display queue
    k_work_submit_to_queue(&display_work_q, &display_item.work);
}

int index;
#define MAX_STRINGS 3
char text[MAX_STRINGS][32]= {
  "Anuj Deshpande",
  "anujdeshpande.com",
  "Interested in developer tools!"
};

void badge_init_entry(void* arg)
{
  LOG_INF("Badge init entry");
  if (!device_is_ready(strip)){
    LOG_ERR("LED strip not ready");
    return ;
  }
  LOG_INF("LED strip ready. Use shell command: led r/g/b");
  set_led_color(RGB(0x0F, 0x0F, 0x0F)); // Default: white
  // Initialize display work queue
  k_work_queue_init(&display_work_q);
  k_work_queue_start(&display_work_q, display_stack, K_THREAD_STACK_SIZEOF(display_stack),
                    K_PRIO_COOP(7), NULL);

  // Initialize display work item
  k_work_init(&display_item.work, display_work_handler);
  display_item.update_text = false;

  display_dev = DEVICE_DT_GET(DT_CHOSEN(zephyr_display));
  if (!device_is_ready(display_dev)) {
    printk("Display_Device %s not ready\n", display_dev->name);
    smf_set_state(SMF_CTX(&s_obj), &badge_states[BADGE_STATE_ERROR]);
    gen_event(BADGE_EVENT_DISPLAY_ERROR);
    return;
  }

  LOG_INF("SSD1306 device found\n");
  display_init();

  // Initialize Bluetooth
  int err = ble_init();
  if (err) {
    LOG_ERR("Bluetooth initialization failed");
    smf_set_state(SMF_CTX(&s_obj), &badge_states[BADGE_STATE_ERROR]);
    gen_event(BADGE_EVENT_BLE_ERROR);
    return;
  }

  smf_set_state(SMF_CTX(&s_obj), &badge_states[BADGE_STATE_IDLE]);
}

void badge_init_exit(void* arg)
{
  LOG_INF("Badge init exit");
}

void badge_idle_entry(void* arg)
{
  LOG_INF("Badge idle entry");
  display_text("Makerville Badge MS!");
}

void badge_idle_run(void* arg)
{
  struct s_object *obj = (struct s_object *)arg;

  switch(obj->event) {
    case BADGE_EVENT_SHORT_BUTTON_PRESS:
      LOG_INF("Short button pressed when IDLE");
      display_text("Short button press");
      break;
    case BADGE_EVENT_LONG_BUTTON_PRESS:
      LOG_INF("Long button pressed when IDLE");
      display_text("Long button press");
      break;
    case BADGE_EVENT_BLE_ERROR:
      smf_set_state(SMF_CTX(&s_obj), &badge_states[BADGE_STATE_ERROR]);
      gen_event(BADGE_EVENT_BLE_ERROR);
      break;
    default:
      LOG_INF("Unhandled event in idle state %d", obj->event);
      break;
  }
}

void badge_idle_exit(void* arg)
{
  LOG_INF("Badge idle exit");
}

void badge_error_entry(void* arg)
{
  LOG_INF("Badge error entry");
}

void badge_error_run(void* arg)
{

  struct s_object *obj = (struct s_object *)arg;
  switch(obj->event) {
    case BADGE_EVENT_DISPLAY_ERROR:
      LOG_INF("Display error - can only show this");
      break;
    case BADGE_EVENT_BLE_ERROR:
      display_text("BLE error");
      break;
    default:
      LOG_INF("Unhandled event in error state %d", obj->event);
      break;
  }
}

void badge_error_exit(void* arg)
{
  LOG_INF("Badge error exit");
}

static const struct smf_state badge_states[] = {
  [BADGE_STATE_INIT] = SMF_CREATE_STATE(badge_init_entry, NULL, NULL,NULL,NULL),
  [BADGE_STATE_IDLE] = SMF_CREATE_STATE(badge_idle_entry, badge_idle_run, badge_idle_exit,NULL,NULL),
  [BADGE_STATE_ERROR] = SMF_CREATE_STATE(badge_error_entry, badge_error_run, badge_error_exit,NULL,NULL),
};

void input_cb(struct input_event *event, void *cb_arg)
{
    if (event->type == INPUT_EV_KEY) {
        if (event->code == INPUT_KEY_0) {
            if (event->value == 1) {
                // Button pressed
                LOG_INF("Button pressed");
                gc.button_press_time = k_uptime_get();
            } else if (event->value == 0) {
                // Button released
                LOG_INF("Button released");
                int64_t press_duration = k_uptime_get() - gc.button_press_time;
                if(press_duration > 1000) {
                  LOG_INF("Long button press");
                  gen_event(BADGE_EVENT_LONG_BUTTON_PRESS);
                } else {
                  LOG_INF("Short button press");
                  gen_event(BADGE_EVENT_SHORT_BUTTON_PRESS);
                }
            }
        }
    }
}

INPUT_CALLBACK_DEFINE(NULL, input_cb,NULL);
int main(void)
{
  int32_t ret;
  int rc;

  smf_set_initial(SMF_CTX(&s_obj), &badge_states[BADGE_STATE_INIT]);
  while(1) {
    rc = k_msgq_get(&event_msgq, &s_obj.event, K_NO_WAIT);
    if(rc == 0) {
      ret = smf_run_state(SMF_CTX(&s_obj));
      if (ret != 0) {
        LOG_ERR("SMF error: %d", ret);
      }
    }
    k_msleep(10);
  }
  return 0;
}

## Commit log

2025-02-26 Add button code (commented as buggy)
    Seeing i2c crashes when button enabled - not sure why yet
    [main.c]
2025-02-26 Use pin 7 for i2c - pin 9 used for onboard button
2025-02-27 Cycle through strings on button
2025-03-05 schematic v1 WIP
    [ESP32-C3-MINI-1-N4--3DModel-STEP-1.step, OLED_0.91_128x32.stp, USB4105-GF-A.step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]
2025-03-09 v1 draft PCB layout
    [mbadge25.kicad_pcb, mbadge25.kicad_sch]
2025-03-17 v2 draft PCB layout
    [Adafruit USB Type C Downstream Breakout rev B.kicad_pcb, Adafruit USB Type C Downstream Breakout rev B.step, USB-C_BO.FCStd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]
2025-03-18 draft PCB layout WIP
    [mbadge25.kicad_pcb, mbadge25.kicad_sch]
2025-03-20 changed PCB dims, rearranged components
    [mbadge25.kicad_pcb, mbadge25.kicad_sch]
2025-03-21 PCB routing done, labels added
    [MakervilleBadgeRepo.dxf]
2025-03-23 simple sandwich enclosure design
2025-03-26 PCB updates
    [mbadge25.kicad_sch]
2025-03-28 Fix typo on silksceen
    [mbadge25.kicad_pcb]
2025-03-30 iBoM and Render updates
    [mbadge25.kicad_pcb]
2025-05-16 Use usb serial for console, swap i2c pins based on schem
2025-05-17 Rename build file, check val before calling button callback
2025-05-17 mBadge_v2 updates : * Added v2 folder for hw_pcb * Added pull up for IO2 * Added pull up for IO8 (I2C) * Added pull up for IO7 (I2C) * Changed R6 from 100k to 10k * Legend, Replaced v1 with v2 * Lege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
    [makerville_logo.dxf, mbadge25.kicad_sch]
2025-05-21 Add enclosure
    [badge.scad]
2025-05-22 Add buttons
    [badge.scad, button.stl]
2025-05-22 Add single STL
    [button.stl]
2025-05-22 Accept button input during scroll
2025-05-26 Move to input subsys, have short and long button press events
    [main.c]
2025-06-04 Try restarting the advertising after a disconnect
    Fails with error -12 - need to dig more
    [main.c]
2025-07-04 - Replaced D1. Previous MPN: MSK4005 (SOD-523) New MPN: B0520LW-7-F (SOD-123). - Replaced U2. Previous MPN : XC6220B331MR New MPN: AP7366-33W5-7. - Updated Mfr. Part Number for all components. - Adde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
    [mbadge25.kicad_sch]
2025-10-15 Enable LED strip
2025-10-15 Add Neopixel LED support with shell command
2025-10-30 Move led init to badge init, accept values between 0 and 255
